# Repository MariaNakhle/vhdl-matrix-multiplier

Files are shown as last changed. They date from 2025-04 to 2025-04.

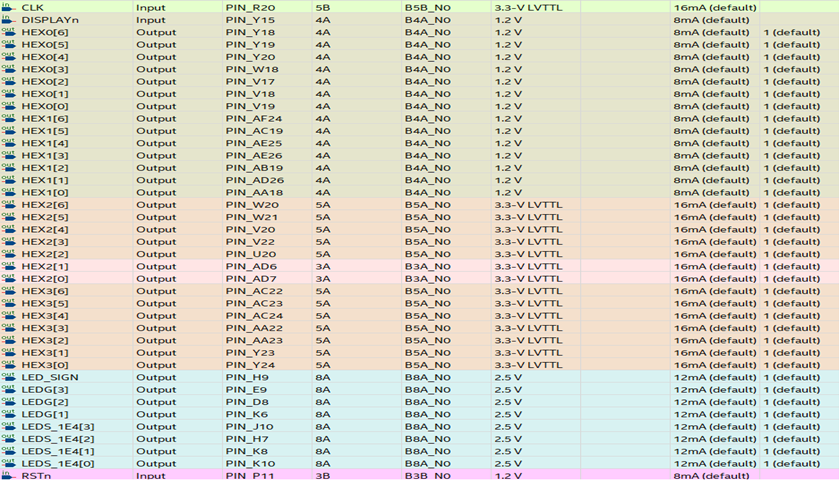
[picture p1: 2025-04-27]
assets/hardware_setup.png

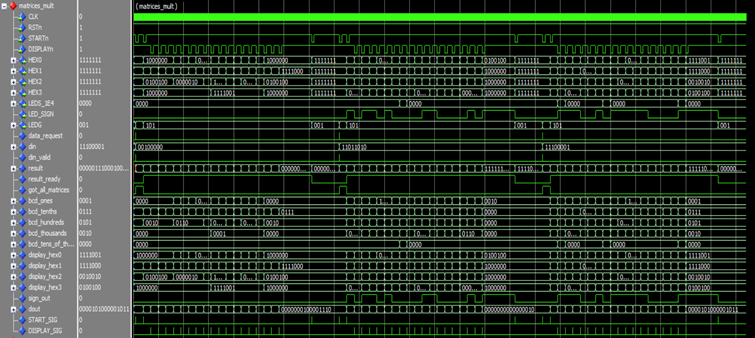
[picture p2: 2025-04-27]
assets/simulation_waveform.png

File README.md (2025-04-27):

# VHDL Matrix Multiplier - Final Project 🖩⚡

This repository contains my final project for the *Programmable Logic Devices* course at Braude College. The project demonstrates a fully functional **4×4 matrix multiplier** designed in VHDL, simulated in ModelSim, synthesized with Quartus Prime, and deployed on an Altera Cyclone V FPGA board.

---

## 📚 Project Overview

The system multiplies two signed 4×4 matrices and displays the resulting matrix on 7-segment displays. The design uses modular components, state machines, and efficient resource allocation.

---

## 🚦 Workflow

### 1. **Input Phase**
- Two 4×4 matrices are provided using a data generator.
- A `START` signal initiates the input process, storing both matrices in memory.

### 2. **Computation Phase**
- The matrix multiplier module performs the multiplication.
- The resulting matrix is saved for output.

### 3. **Output Phase**
- The result is shown on 7-segment displays.
- Additional LEDs indicate values that exceed the display range.

### 4. **Reset/Restart Phase**
- Pressing the `START` button resets the system for a new operation.

---

## 🎮 Features

### 1. Modes of Operation

- **Idle Mode:** System initializes and waits for input.
- **Input Mode:** Sequentially captures matrix elements.
- **Compute Mode:** Executes the multiplication efficiently.
- **Display Mode:** Presents each result element with navigation controls.

### 2. Control Signals

- `START`: Triggers input, computation, or resets the system.
- `DISPLAY`: Steps through the result one element at a time.

---

## 📜 Documentation

- **Project Requirements:** System requirements, design goals, and implementation plan. *(docs/Project_Requirements.pdf)*
- **Final Project Report:** Detailed explanation of design, simulation, synthesis, and conclusions. *(docs/Final_Report.pdf)*

---

## 🖼️ Visuals

### 1. System Block Diagram

A high-level overview showing the Data Generator, Matrix Multiplier, and Main Controller modules.

*Insert "Block Diagram" image here*

### 2. State Machine Diagram

- Main Controller FSM: Manages operation modes.
- Multiplier FSM: Handles multiplication steps.

*Insert "Main State Machine" and "Multiply State Machine" images here*

### 3. Simulation Results

- Example simulation waveform showing matrix multiplication outputs.

*Insert "Simulation Waveform" image here*

### 4. FPGA Hardware Setup

- Photo or schematic of the project on the Altera Cyclone V FPGA board.

*Insert "Hardware Setup" image here*

---

## 🎥 Demonstration Video

Check out a demo of the project in action:

- [Watch Matrices Multiply Video]([link-to-video](https://www.youtube.com/embed/o8P8AF92zM4?feature=oembed))
  
---

## 📂 Repository Structure

```
.
├── README.md
├── LICENSE
├── docs/
│   ├── Project_Requirements.pdf
│   └── Final_Report.pdf
├── src/                  # VHDL source files
├── tb/                   # Testbenches
├── assets/               # Block diagrams, waveforms, photos
└── reports/              # Simulation and synthesis results
```

---

## 👨‍💻 Author

- Maria

---

## 🔭 Future Improvements

- [ ] Support for larger matrices
- [ ] Pipelined or parallelized architecture
- [ ] Enhanced user interface and display modes

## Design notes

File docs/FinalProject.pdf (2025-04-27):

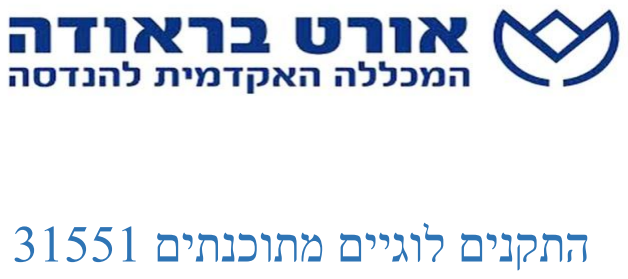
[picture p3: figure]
התקנים לוגיים מתוכנתים 31551

דוח מסכם

מגישות:

## היבא חמדאן

גנא שלבי
מריה נחלה

תאריך הגשה : 6/09/2024

מחלקה: הנדסת חשמל ואלקטרוניקה

שם המדריך: ד"ר פאדל טריף

## תוכן העניינים

.1 דרישות תכן 3 |
.2 קיצור לפעולת הבלוקים 4-5 |
.3 מימוש הרמה העליונה mult_matrices6-10 |
3.1 מבנה לוגי | 6 |
3.2 מימיוש הקוב בשפת VHDL7-9 |
10 | Pin Planner 3.3
11-16 | …Main_controller | מימוש | .4
3.1 מבנה לוגי | 11 |
3.2 מימיוש הקוב בשפת VHDL12-15 |
3.2 מכונת מצבים מתוכנתים16 |
.5 תוצאות RTL netlist Viewer עבור כל בלוק16-20 |
.6 ניצול משאבים : 21 |
.7 תוצאות ניתוח Timming22 |
.8 תוצאות מעניינות של signalTAB 23-24 |
8.1 מטריצה A | 23 |
8.2 מטריצה C | 24 |
24 | RST 8.2
.9 סרטון | 25 |
.10 סיכום | 25 |

## .1 דרישות תכן :

המערכת מופעלת משעון יחיד של 50MHz. כניסה: לחצן low active — RESET — מגיע מהלחצן שברכבה. יציאה: תצוגת מצב המערכת. מצב כל ה-LEDs ותצוגת 7n-seg יהיו כבויים למעט )1(LEDG שנמצא בכל אחד ממצבי המערכת.
לחיצה ראשונה על לחצן STARTn גורמת לבלוק generator_data להתחיל להוציא את שני המטריצות. קצב הצגת 16 האיברים בכל מטריצה הוא תוצאה ללחיצה הראשונה ולאחר כל 16 האיברים של המטריצה קדימה או אחורה המערכת עוצרת ומחכה ללחיצה נוספת. בזמן קבלת המטריצות המערכת מתעלמת מלחיצות על הלחצנים STARTn -1DISPLAYn. גודל המטריצות 44x כאשר כל איבר במטריצה הוא מספר של 8 signed bits( מספרים מוסומנים בין - 127 ל127+(.
התוצאה תרשם בזיכרון בסדר שהוכן בזיכרון לאחר קבלת תוצאות המטריצות, המערכת תעבור לתצוגת התוצאות.
אם לחצן STARTn נלחץ שוב במהלך תצוגת התוצאות, המערכת תמשיך להתעלם מלחיצות על הלחצנים .STARTn- ו DISPLAYn-1
המערכת תפעל בסבב של שתי מטריצות ותתקבלנה תוצאות גם אם היא לא לחוצה בזמן כתיבת תוצאות. לחיצה על לחצן אחר תגרום לשינוי תצוגת מצב המערכת על ה-LED ותצוגת 7n-seg. במהלך קבלת המטריצות, לחיצה על לחצן אחר לא תגרום לשינוי תצוגת מצב המערכת על ה- LED ותצוגת .seg-n7
לאחר שהתוצאה הראשונה של המטריצות תתקבל ותוצג, תופעל לחיצה נוספת שתפעיל את התצוגה הבאה.
במצב תצוגת המטריצות המערכת חוזרת לתצוגת מצב המערכת על STARTn -1DISPLAYn. המערכת תמשיך בתצוגה זו עד אשר תתקבל תוצאה ברורה )אין אפשרות לבצע קריאת זיכרון וכתיבה לזיכרון בו זמנית(.
במהלך הצגת התוצאה המערכת מציגה את התוצאה באמצעות הלחצנים במטריצה של 7n-seg. לחיצה על כל לחצן אחר תגרום להצגת התוצאה באופן אוטומטי. לחיצה נוספת על לחצן STARTn תגרום להפסקת התצוגה ולהפעלת המערכת מחדש לתחילת התהליך.

## .2 קיצור לפעולת הבלוקים שקיבלנו מד"ר פאדל :

:bcd_to_7seg | הבלוק | מימוש

הקוד ממיר ערך BCD בן 4 ביט ) 0-9( לתצוגת 7 סגמנטים על ידי קביעת אילו סגמנטים ידלקו עבור כל ספרה.
מימוש הבלוק generator_data :

הבלוק מתפקד כגנרטור נתונים שמייצר ומעביר נתונים מחוץ לרכיב בצורה מאורגנת ומבוקרת, כאשר כל פעם שמתקבל REQUEST_DATA, הוא שולח סדרה של נתונים מהמטריצות שלו דרך האות DOUT.
:bin2bcd_12bit | הבלוק | מימוש

ממיר מספר בינארי בגודל 16 סיב ית )12 סיביות לוגיות בלבד( לפורמט BCD עם 5 ספרות )כולל עשרות אלפים, אלפים, מאות, עשרות, ויחידות(.

מימוש הבלוק convert_num:

הרכיב לוקח מספר בינארי עם סימן, מפריד את הסימן וממיר את המספר לחיובי, ומוציא את התוצאה יחד עם הסימן המקורי. מימוש הבלוק diff_synic:

הרכיב מסנכרן אות כניסה אסינכרוני עם שעון המערכת ומפיק פלט שמציין שינוי באות בהתאם להגדרה.
מימוש הבלוק ram_matrix:

הקוד מייצג רכיב זיכרון RAM שניתן לכתוב ולקרוא ממנו נתונים על פי כתובת.

מימוש הבלוק multiplier_my:

הרכיב מבצע כפל בין שני מספרים בינאריים.

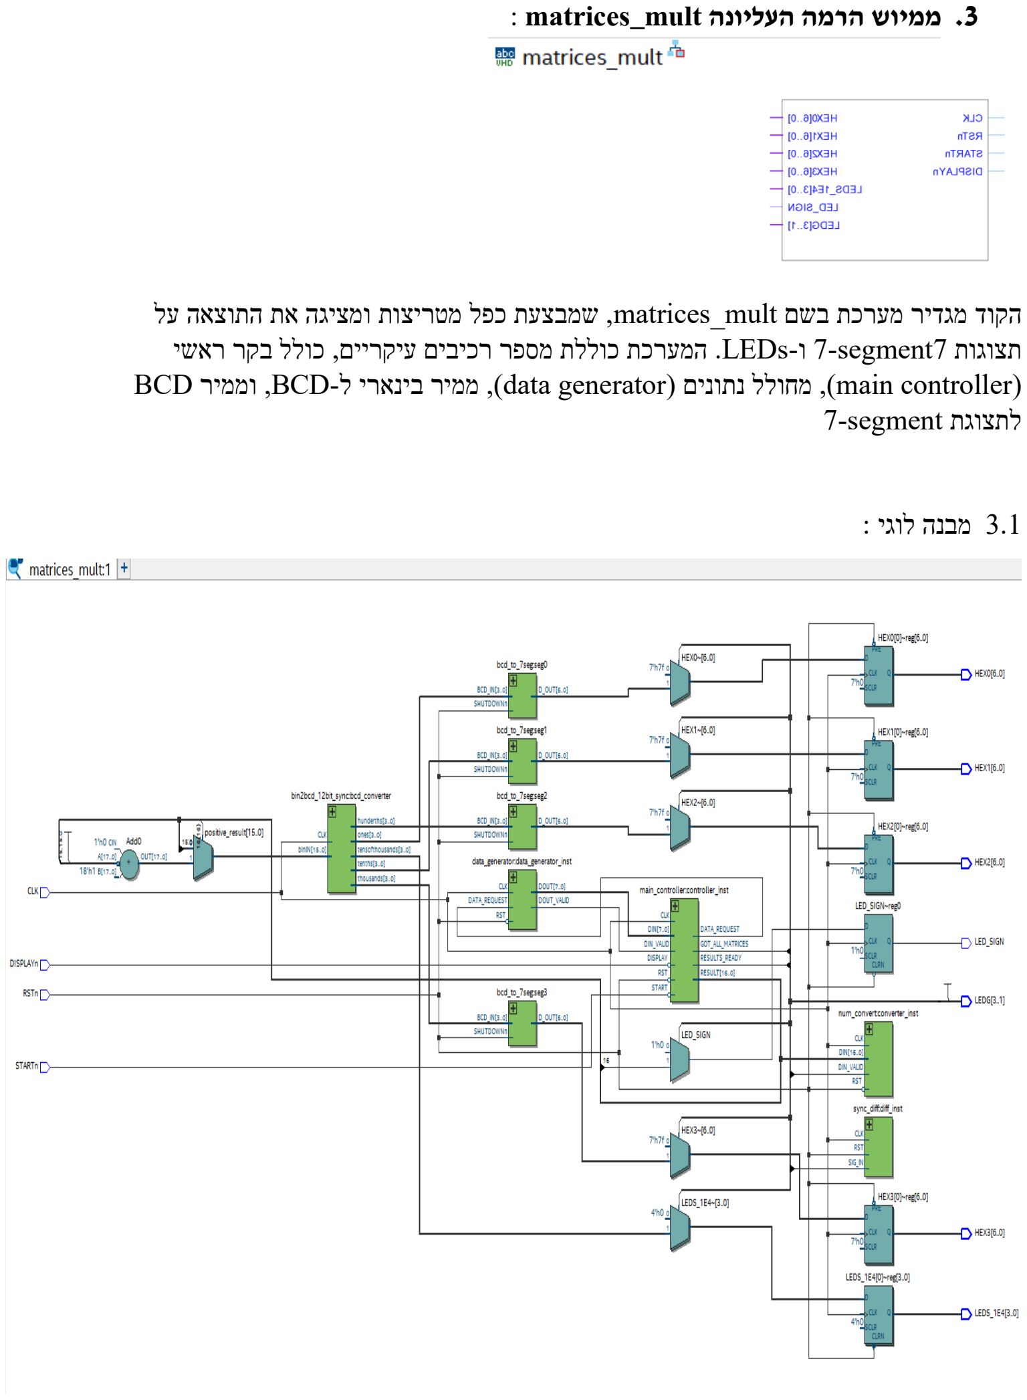
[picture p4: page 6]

.3 ממיוש הרמה העליונה mult_matrices :

הקוד מגדיר מערכת בשם mult_matrices, שמבצעת כפל מטריצות ומציגה את התוצאה על תצוגות 7segment7- ו-LEDs. המערכת כוללת מספר רכיבים עיקריים, כולל בקר ראשי )controller main), מחולל נתונים )generator data), ממיר בינארי ל-BCD, וממיר BCD לתצוגת segment7-

3.1 מבנה לוגי :

: matrices_mult.vhd | קובץ | 3.2

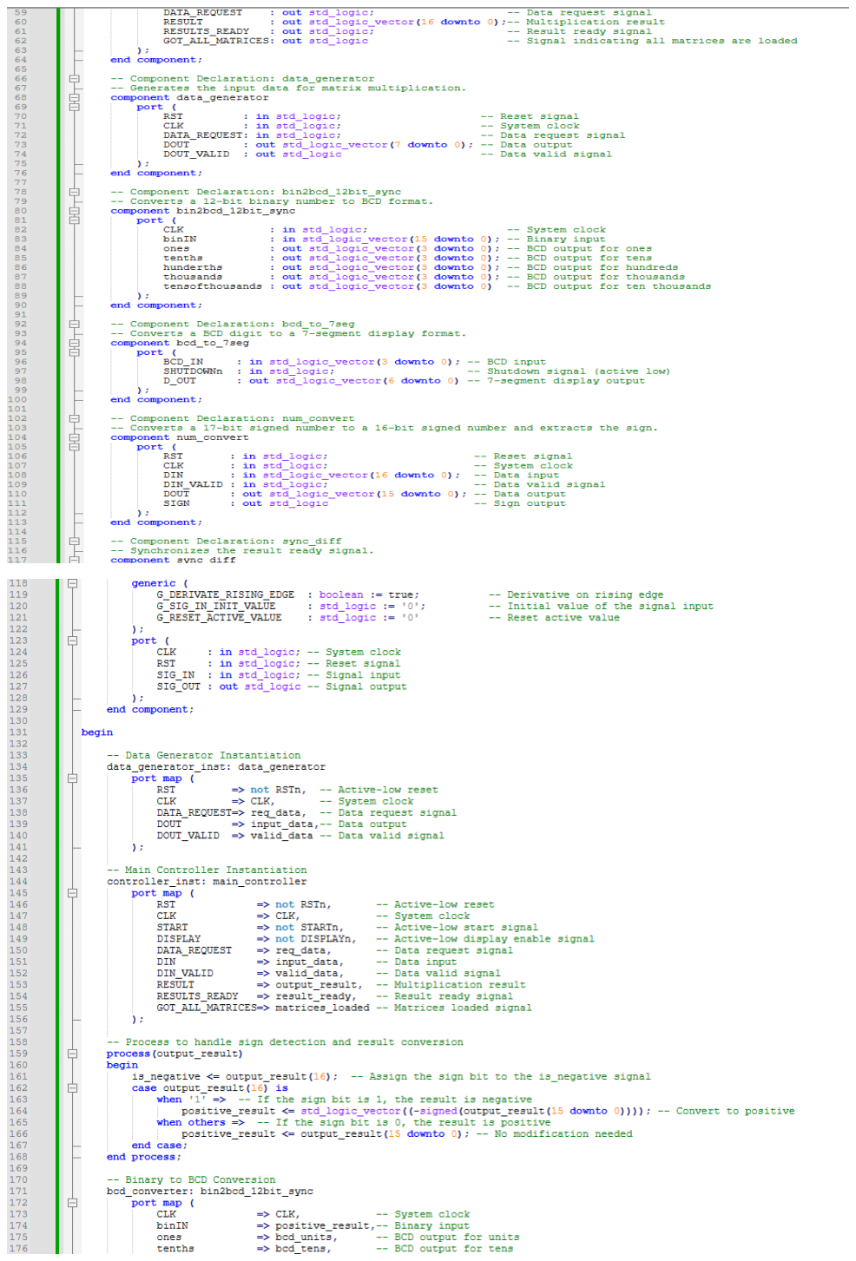
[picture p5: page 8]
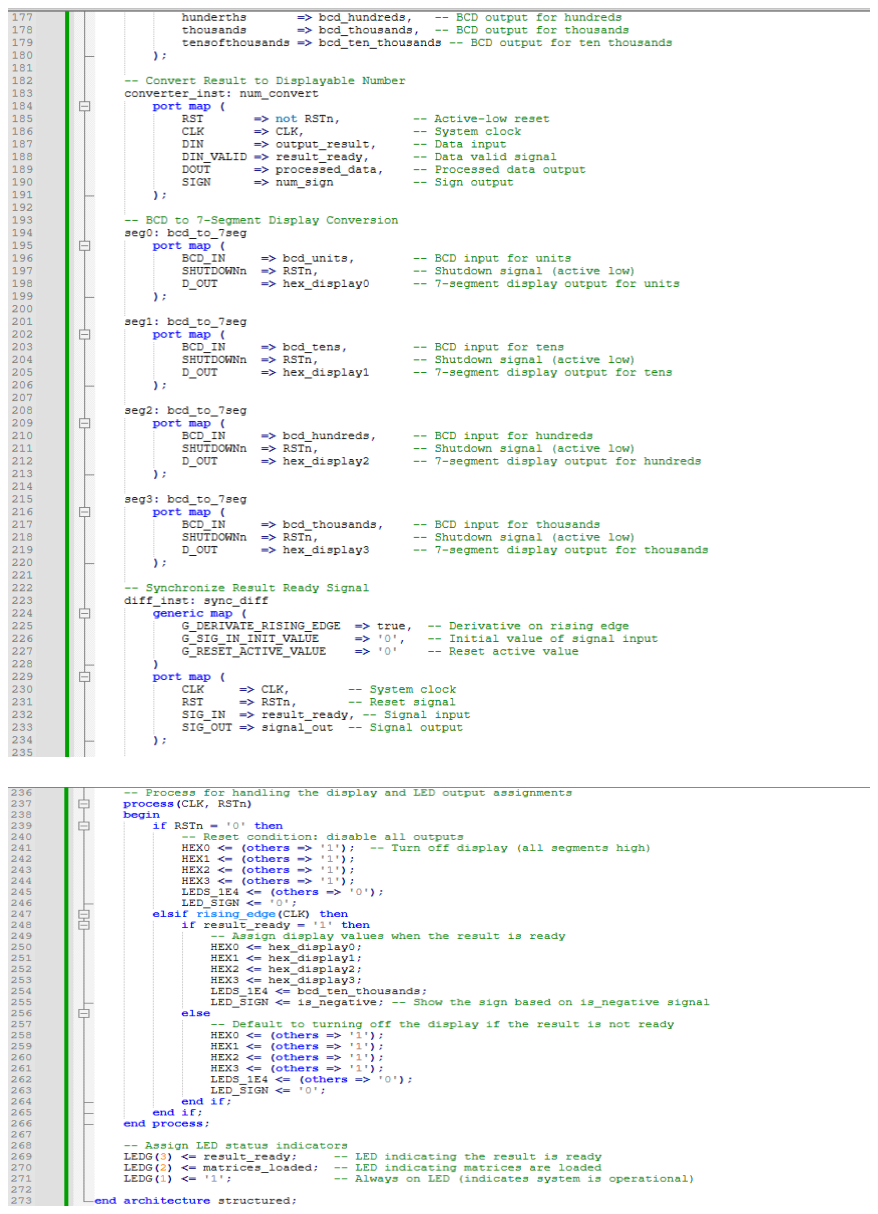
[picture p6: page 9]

## : Pin Planner 3.3

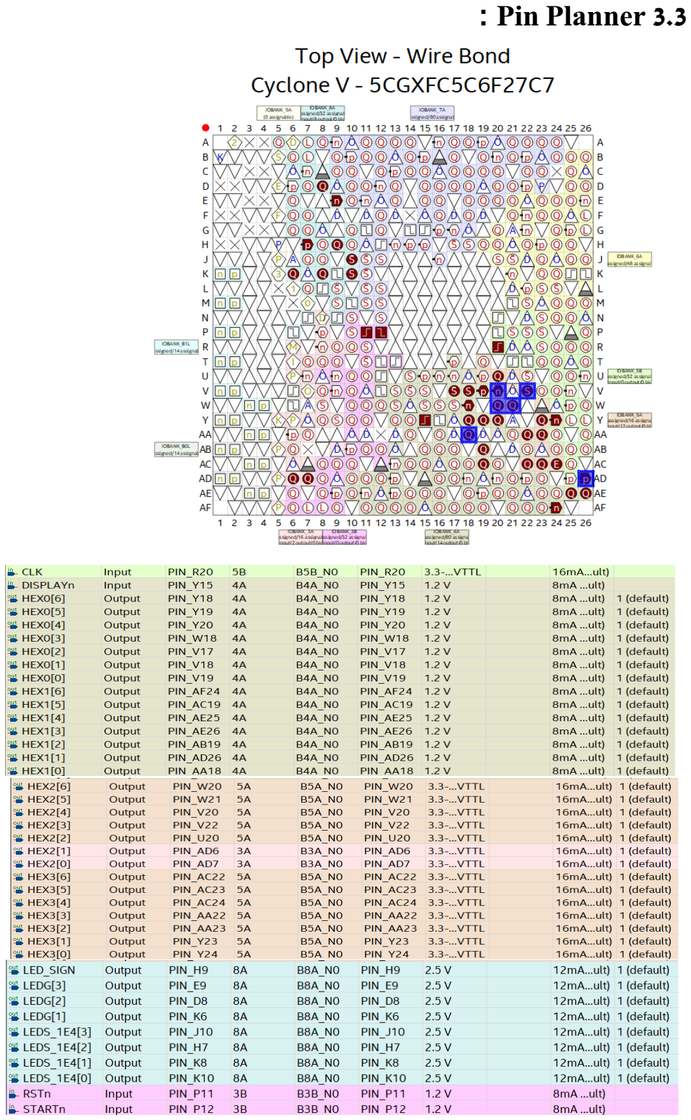
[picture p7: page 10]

.4 מימוש הבלוק controller_main:

הבלוק controller_main הוא רכיב הבקרה המרכזי של המערכת, והוא אחראי על ניהול כל תהליך כפל המטריצות והצגת התוצאות על תצוגות segment7- ו- LEDs. הבלוק מקבל את הפקודות מהמשתמש באמצעות לחצנים )DISPLAY ,START )לאחר שעוברים תהליך של סנכרון וזיהוי עליות אותות, ופועל בהתאם לפקודות שניתנו,הבלוק שולח פולס של REQUEST_DATA לבלוק generator_data כדי לבקש את נתוני המטריצות. לאחר מכן, הבלוק מתחיל לקלוט את המידע ולהעבירו לזיכרון פנימי לשימוש בחישובים.טוען שתי מטריצות בזיכרון, אחת אחרי השנייה. במהלך שלב זה, הבלוק מעדכן מונים ואינדקסים כדי לעקוב אחרי מיקומי המידע בזיכרון ולוודא שכל הנתונים נטענים בצורה נכונה. עם סיום טעינת המטריצות, הבלוק מאותת באמצעות MATRICES_ALL_GOT שהמטריצות נטענו בהצלחה. הבלוק מנהל את פעולת רכיבי הכפל )multiplier_my )ומוודא שכל תוצאת כפל נשמרת בצורה נכונה בזיכרון
על תצוגות segment7- ו הפעלת נורות LED חיווי בהתאם למצב הנוכחי של התוצאה המחושבת. במידה ותוצאה שנבדקת נמצאה כלא תקינה, תידלק נורת חיווי אדומה )SIGN_LED). כאשר כל המידע מוצג והתהליך מסתיים, לחיצה נוספת על לחצן ההתחלה )START )מאפסת את המערכת ומכבה את כל נורות החיווי )לדים ירוקים ואדום(, ומחזירה את המערכת למצב המתנה ) IDLE).

4.1 מבנה לוגי :

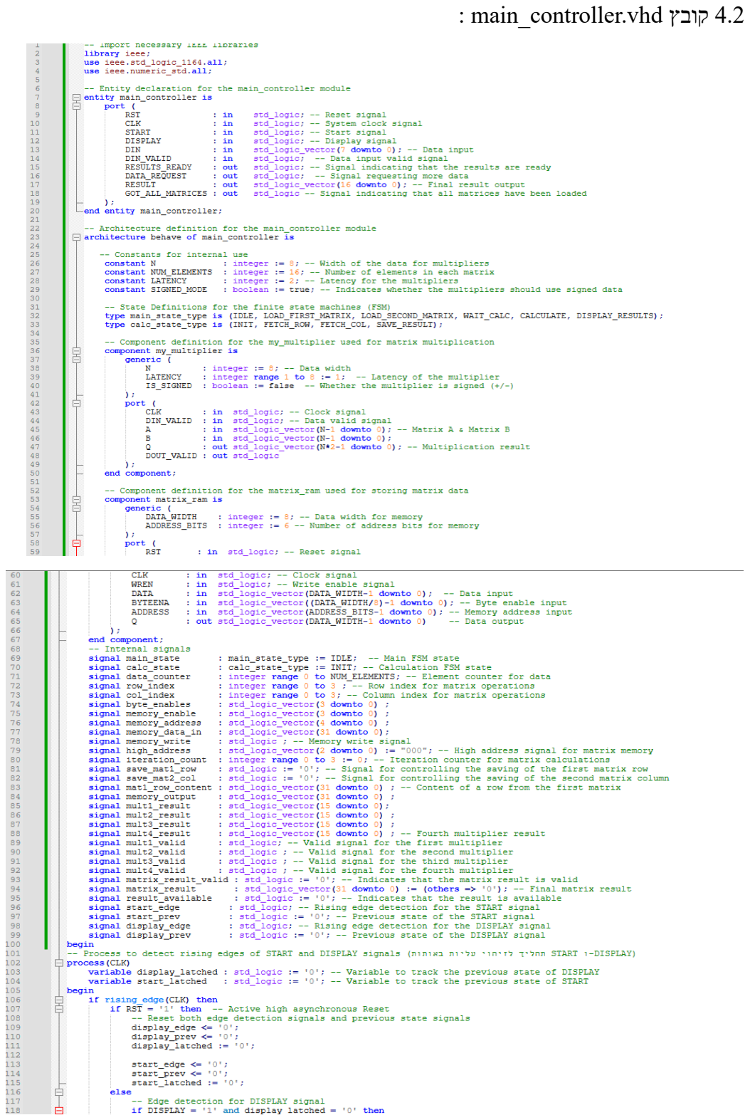
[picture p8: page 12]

: main_controller.vhd | קובץ | 4.2

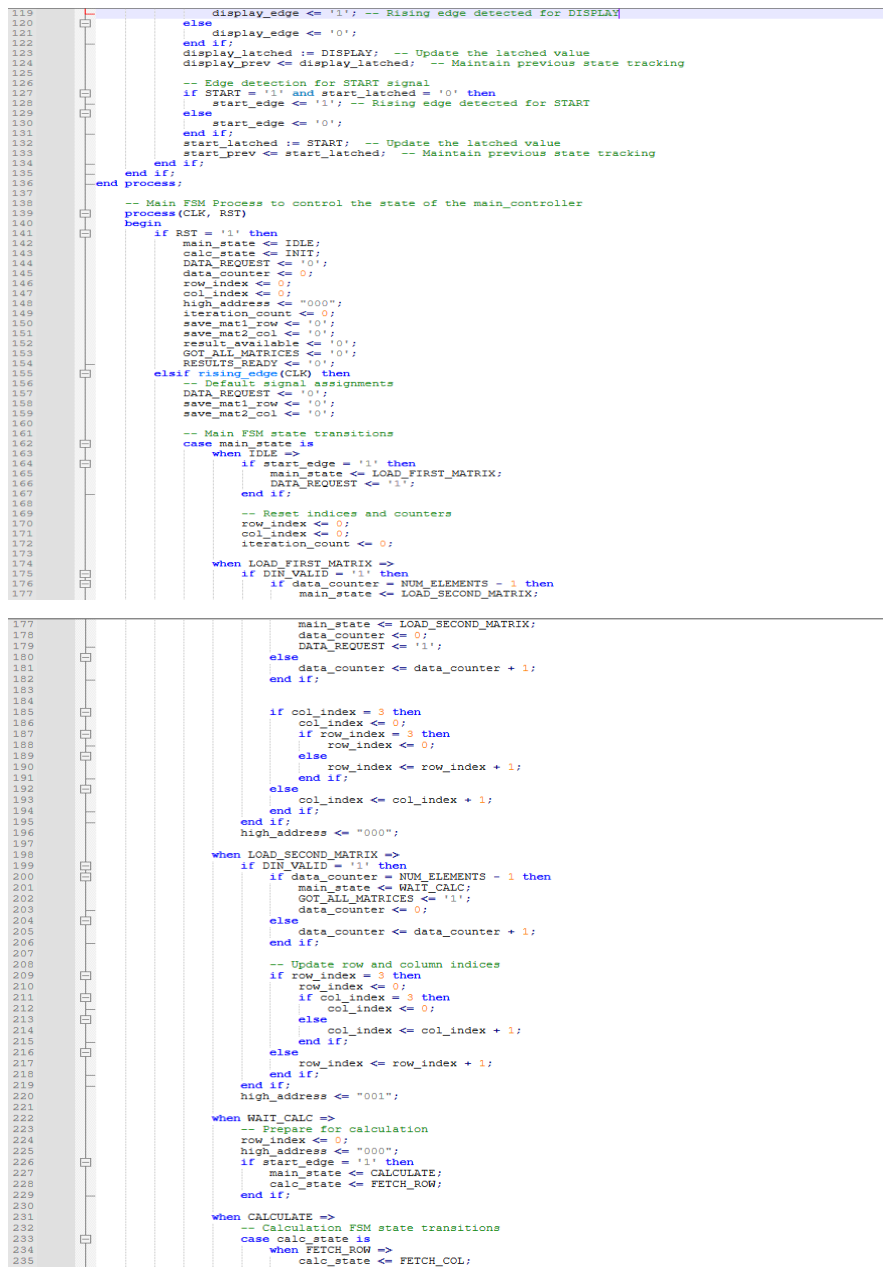
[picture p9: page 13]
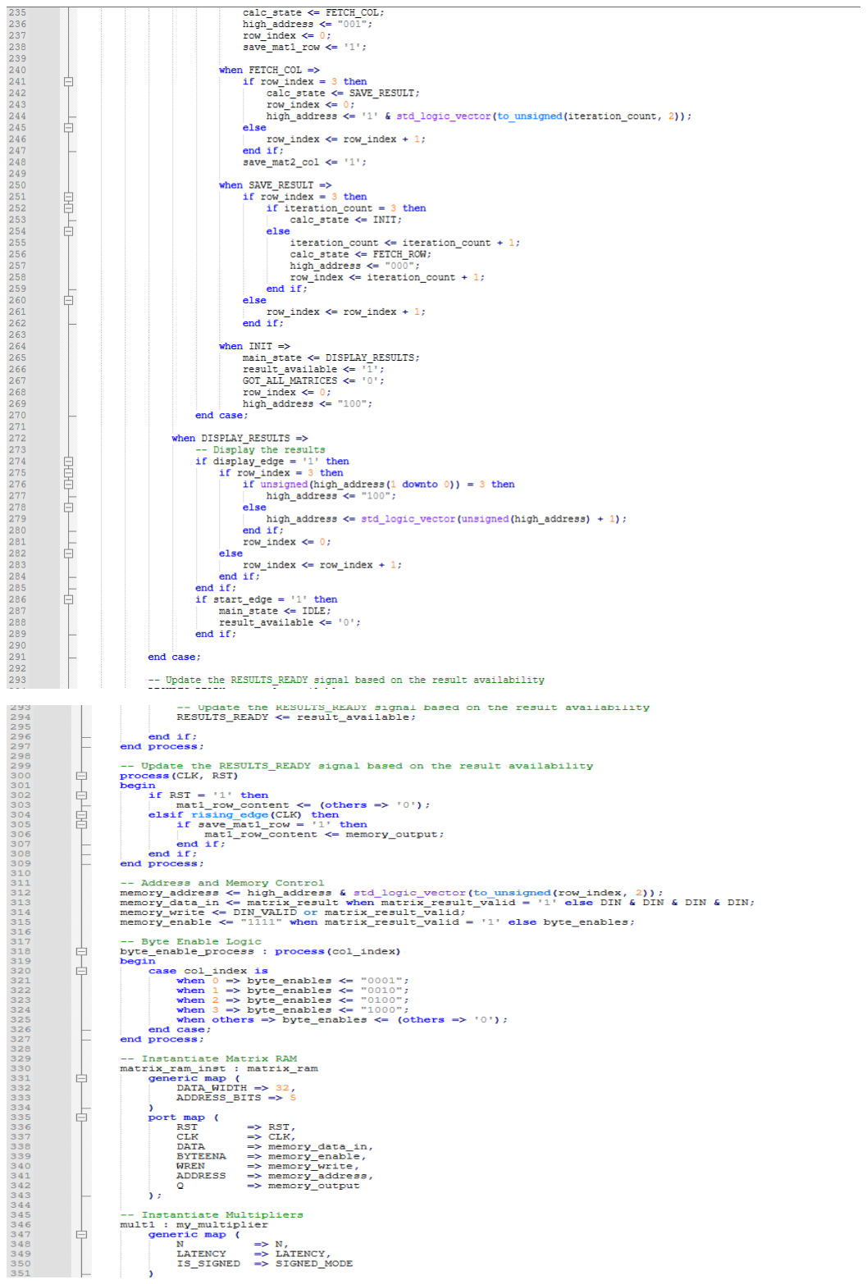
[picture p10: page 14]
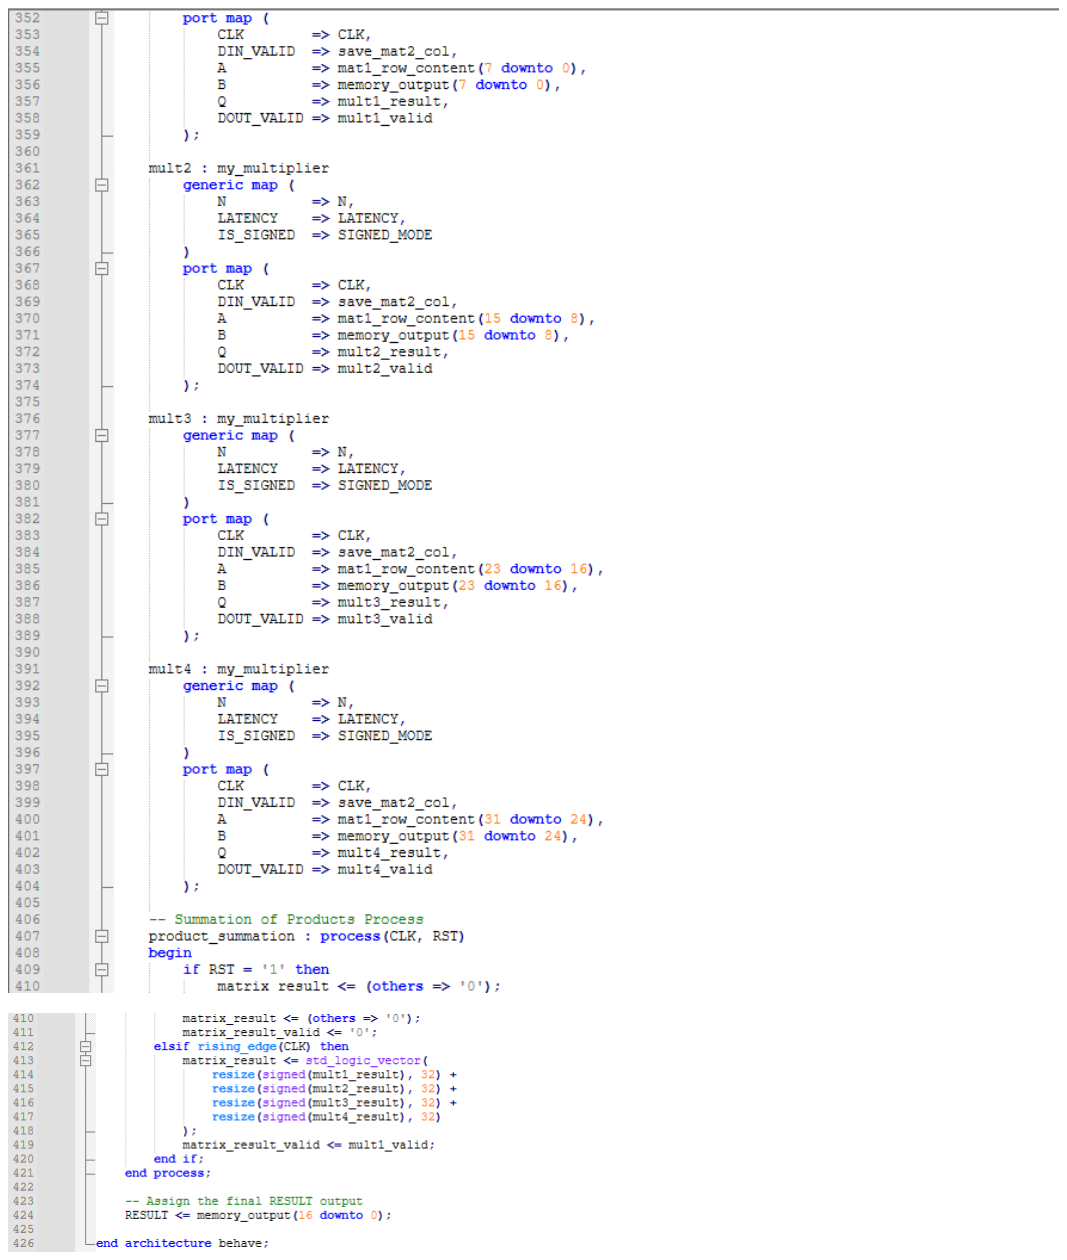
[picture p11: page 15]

### 4.3 מכונות מצבים :

מבנה לוגי 1 :

המערכת מתחילה במצב INIT לאחר שהיא מקבלת פקודת reset .

אם `1`=edge_start המכונה מעבירה ל ROW_FETCH-כדי ל אסוף שורה מהמטריצה הראשונה לאחר איסוף שורה, המכונה מעבירה ל COL_FETCH-כדי לאסוף עמודה מהמטריצה השנייה לאחר איסוף העמודה, אם כל השורות הוקראו המכונה מעבירה ל RESULT_SAVE- שבו שומרים את התוצאות שהתקבלו מהכפל.אם לא כל השורות הוקראו, המכונה ממשיכה לאסוף את שאר השורות.

אם 3=index_row ו 3=count_intration וכל האיטרציות הושלמו המכונה חוזרת ל INIT לשלב הבא של חישוב.
מבנה לוגי 2 :

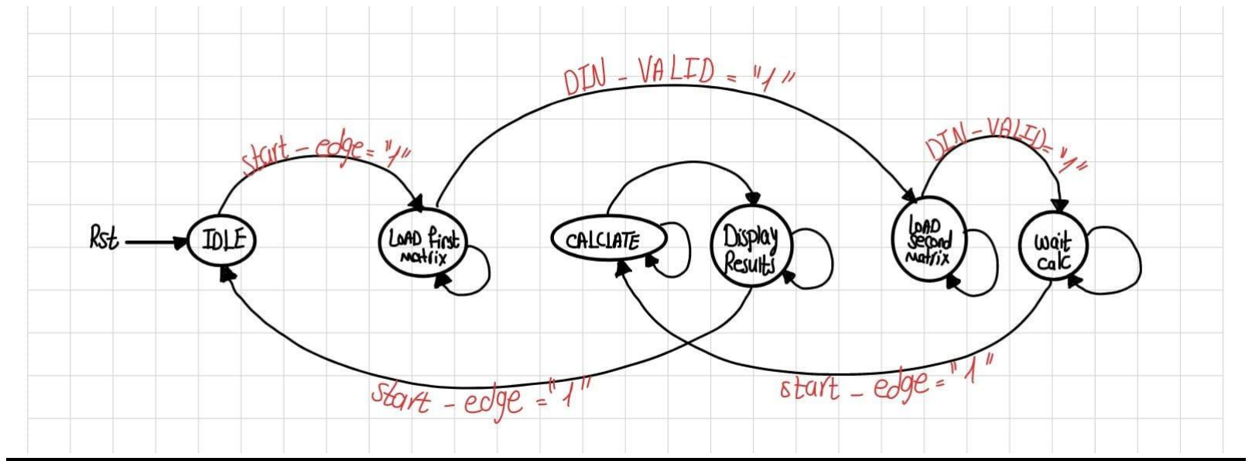
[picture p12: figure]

המערכת מתחילה במצב IDLE לאחר שהיא מקבלת פקודת RST. אם `1`=edge_start המכונה עוברת ל MATRIX_FIRST_LOAD- במצב זה, המערכת טוענת את המטריצה הראשונה כאשר המטריצה הראשונה נטענה בהצלחה אם `1`=VALED_DIN המכונה מעבירה ל.MATRIX_SECOND_LOAD- לטעון את המטריצה השנייה לאחר טעינת המטריצה השנייה, המערכת יכולה להמתין להמשך חישוב במצב CALC_AWAIT. אם `1`=edge_start המערכת עוברת למצב CALCULATE כדי לבצע את החישובים הנדרשים. אם החישוב הושלם ואין צורך במטריצה נוספת, המערכת עוברת למצב RESULTS_DISPLAY להצגת התוצאות. לאחר הצגת התוצאות, המערכת יכולה לחזור למצב IDLE ולהמתין לתהליך חדש או לקבל פקודה נוספת.

## .5 תוצאות RTL netlist viewer עבור כל בלוק והרמה העליונה :

## עבור הרמה העליונה mult_matrices:

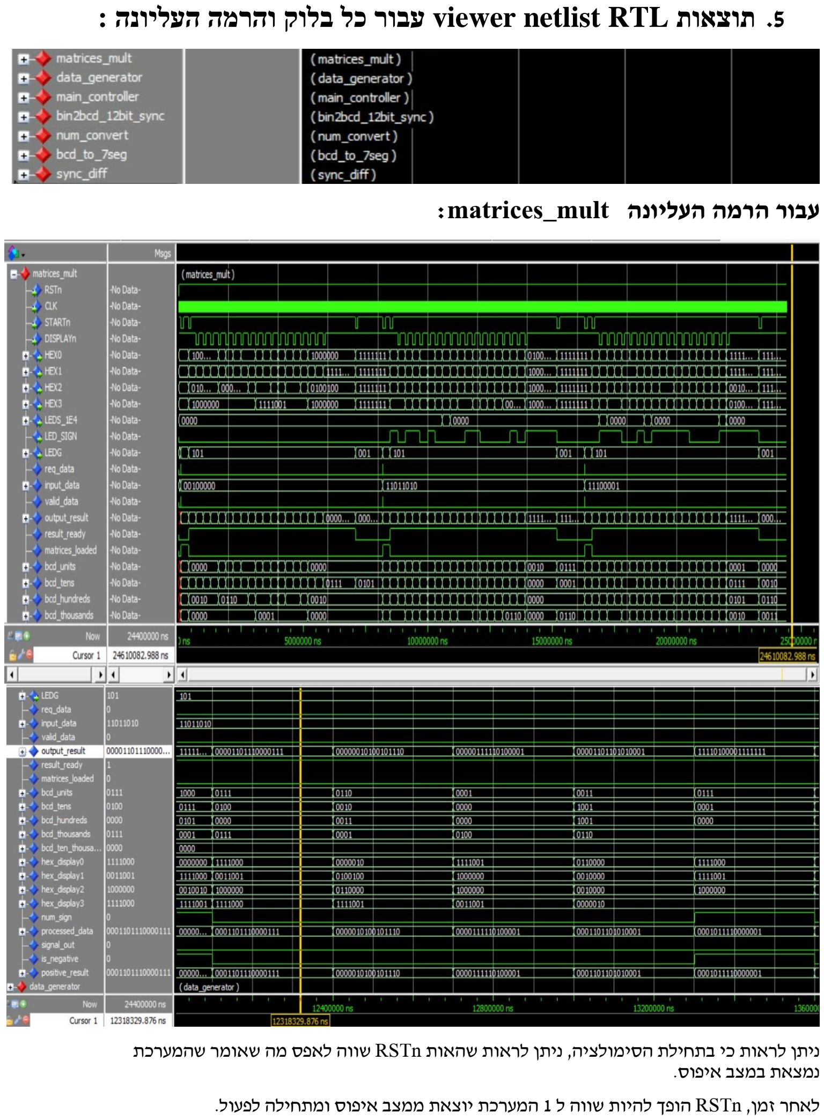
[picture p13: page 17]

ניתן לראות כי בתחילת הסימולציה, ניתן לראות שהאות RSTn שווה לאפס מה שאומר שהמערכת נמצאת במצב איפוס.
לאחר זמן, RSTn הופך להיות שווה ל 1 המערכת יוצאת ממצב איפוס ומתחילה לפעול.

ברגע שכל הנתונים נטענים ) 1 = loaded_matrices), המערכת מתחילה את חישוב כפל המטריצות. ניתן לראות שעם הזמן, result_output מתחיל להשתנות ומציג את התוצאה של כפל המטריצות. כאשר ready_result הופך ל ,1- התוצאה מוכנה להצגה. התוצאות מופיעות על תצוגות segment7-) 3HEX - 0HEX (וה -LEDs בהתאם לערכים המחושבים .)'וכו ,bcd_units, bcd_tens( SIGN_LED מציין את הסימן של התוצאה. 4E1_LEDS מציג את הערך של ספרת עשרת אלפים אם נדרש. LEDG מדליקים את נורות ה-LED המתאימות המציינות שהמערכת פועלת והתוצאה מוכנה.

: data_generator | עבור

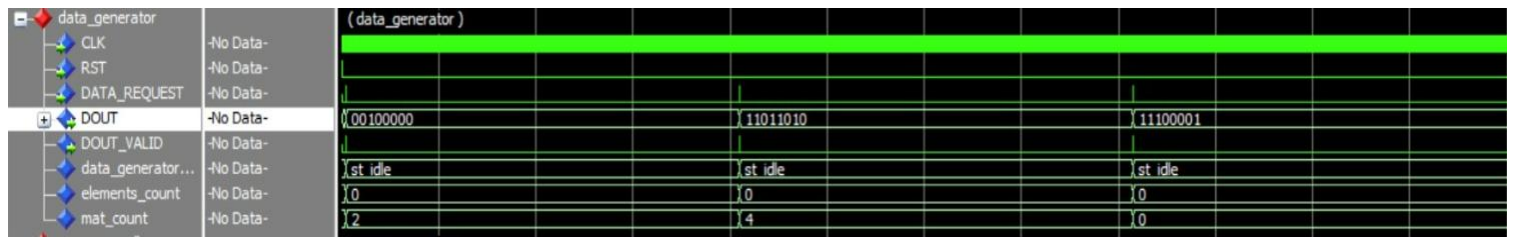
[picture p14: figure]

:synic_diff | עבור

ניתן לראות מסימולציה הפלט מציג את השינויים באות IN_SIG לאחר הסנכרון והגזירה. ו ניתן לראות שהוא מפיק פלט מסונכרן OUT_SIG רק כשהוא מזהה שינוי מתאים ב -IN_SIG.

## :main_controller עבור

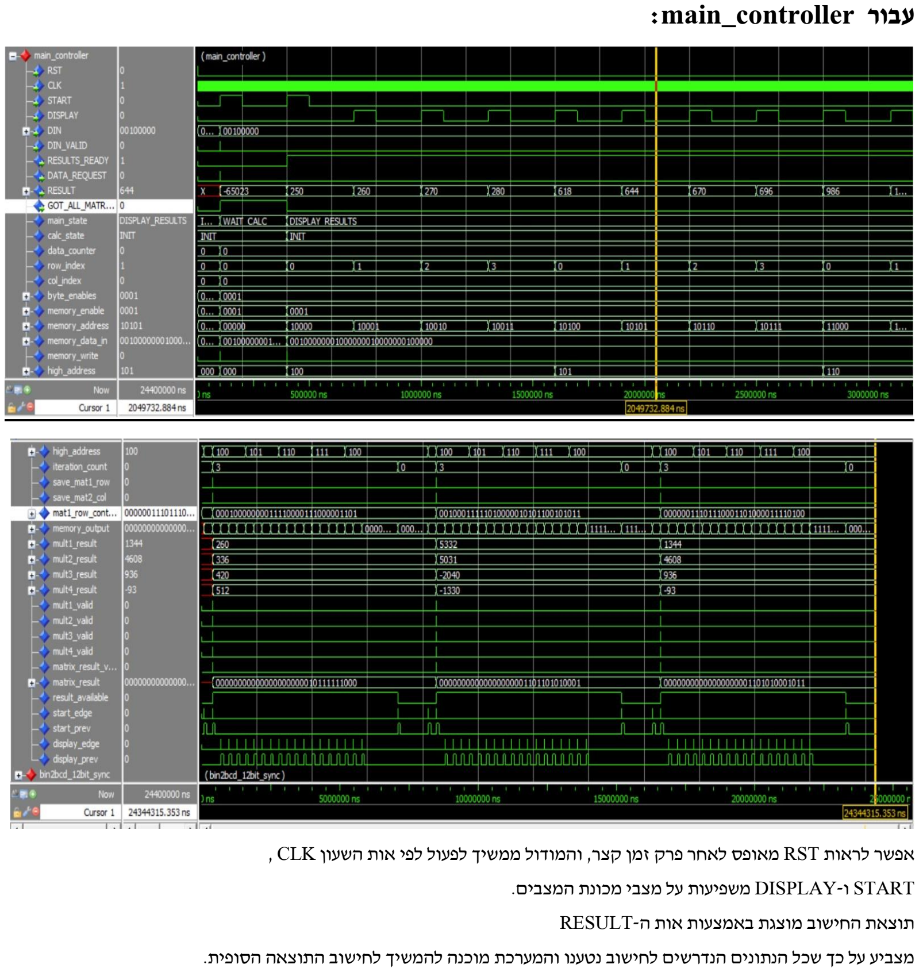
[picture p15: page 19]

אפשר לראות RST מאופס לאחר פרק זמן קצר, והמודול ממשיך לפעול לפי אות השעון CLK ,

START ו-DISPLAY משפיעות על מצבי מכונת המצבים.

תוצאת החישוב מוצגת באמצעות אות ה-RESULT

מצביע על כך שכל הנתונים הנדרשים לחישוב נטענו והמערכת מוכנה להמשיך לחישוב התוצאה הסופית.

:bin2bcd_12bit עבור

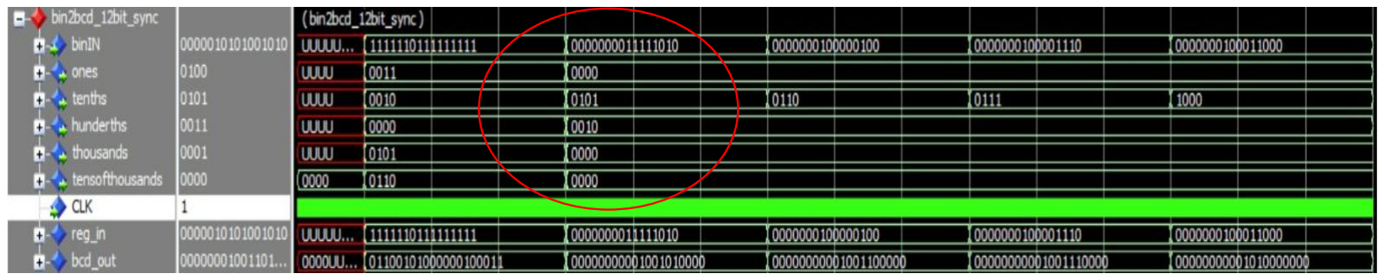
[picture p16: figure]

ניתן לראות מהסימולציה שהוא מממיר המספר הבינארי 0000000011111010 שזה שווה ל 250 בבסיס עשרוני ומפריד אותו לתוך הספרות אחדות עשרות מאות אלפים עשרות האלפים כך ש באחדות מקבלים 0000 )0 בבסיס עשרוני(, עשרות מקבלים 0101 )5 בבסיס עשרוני( מאות 0010 )2 בבסיס עשרוני ( והשאר ממלא אפס .
:num_convert עבור

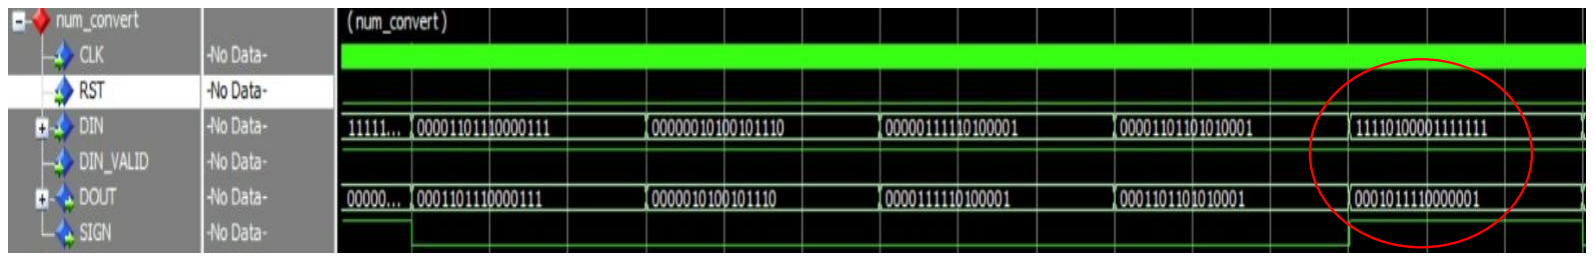
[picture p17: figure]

ניתן לראות מהסימולציה שהמספר החיו בי נשאר אותו דבר ללא שינוי. מתוך העיגול האדום נזהה שהמספר 11110100001111111 זהו מספר שלילי בגלל ביט הסימן )1( נהפוך את כל הביטים ונקבל 0001011110000000 נוסיף 1 למספר המהופך ,0001011110000000 התוצאה היא 0001011110000001 מאחר וזה היה מספר שלילי מקבלים DOUT התוצאה המוחלטת היא 000101111000001 שמייצג את הערך המוחלט של 6017 בעשרוני. :bcd_to_7seg עבור

ניתן לראות בסימולציה כל ערך שנכנס למערכת מתורגם לערך שמסמל איזה לידים צריכים להידלק בצג שעל הערכה (הלדים נדלקים בנמוך).המוצא תלוי ב- SHUTDOWN, כלמור כאשר הוא אפס המצוא יהיה ‘1111111’זאת אומרת ה- segment 7 של הערכה יהיה כבוי, וכאשר ‘1’ = SHUTDOWN המערכת תעבוד בדיוק כמו בסימולציה.

## .6 ניצול משאבים :

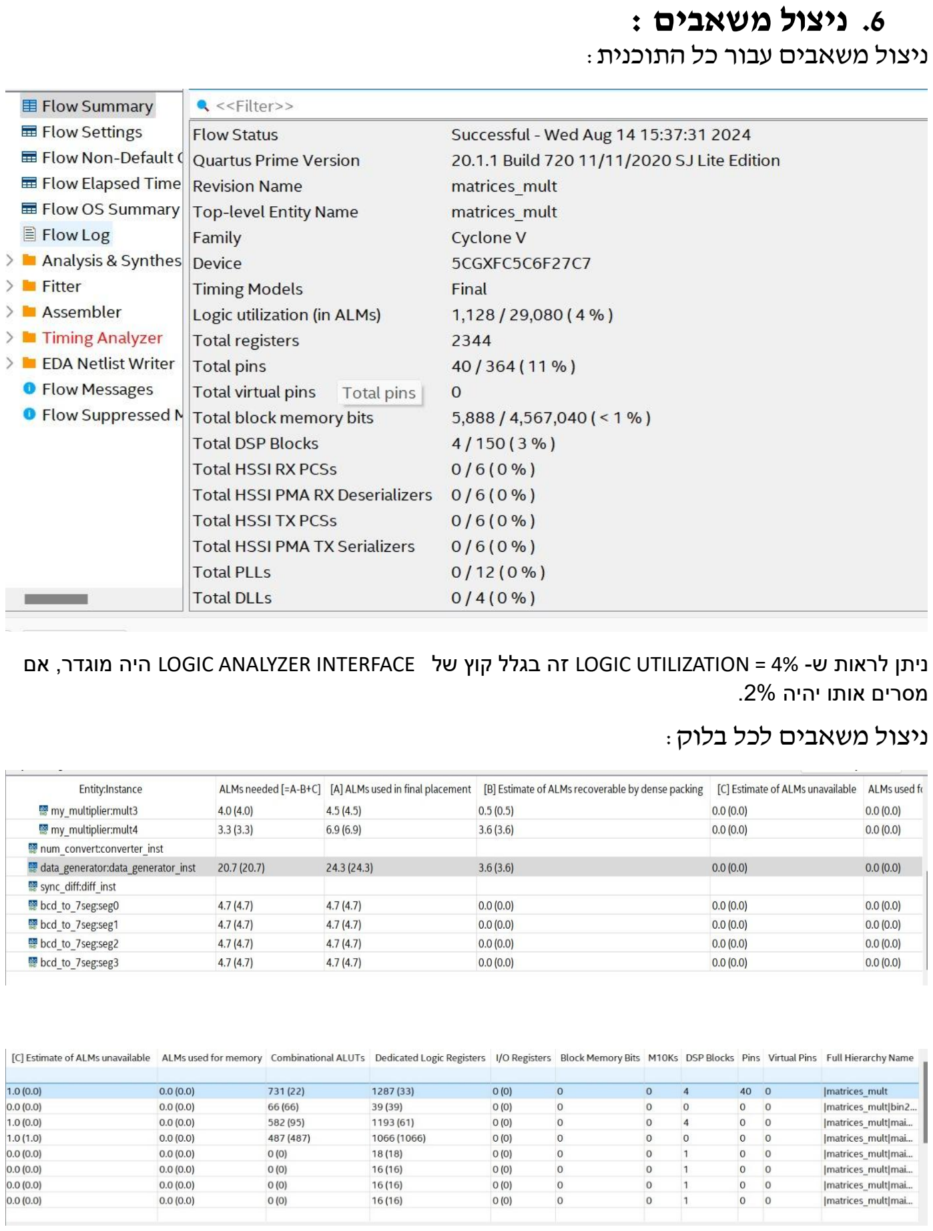
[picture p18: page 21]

ניצול משאבים עבור כל התוכנית:

ניתן לראות ש- 4% = UTILIZATION LOGIC זה בגלל קוץ של INTERFACE ANALYZER LOGIC היה מוגדר, אם מסרים אותו יהיה .2%
ניצול משאבים לכל בלוק:

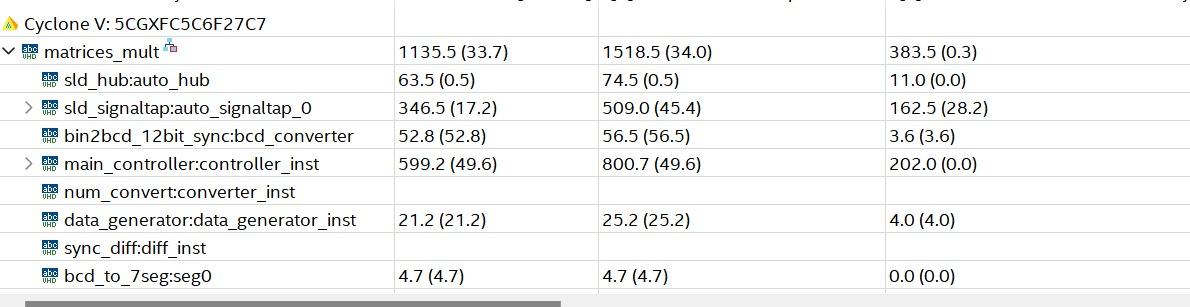
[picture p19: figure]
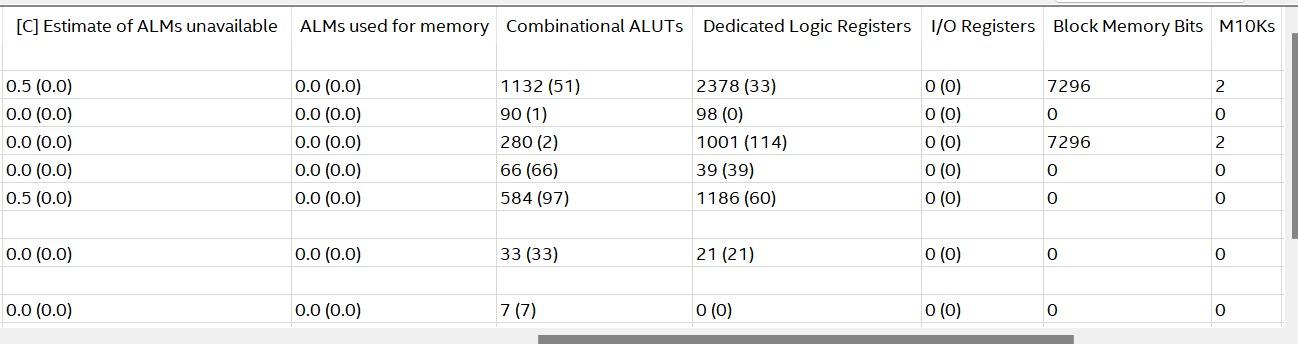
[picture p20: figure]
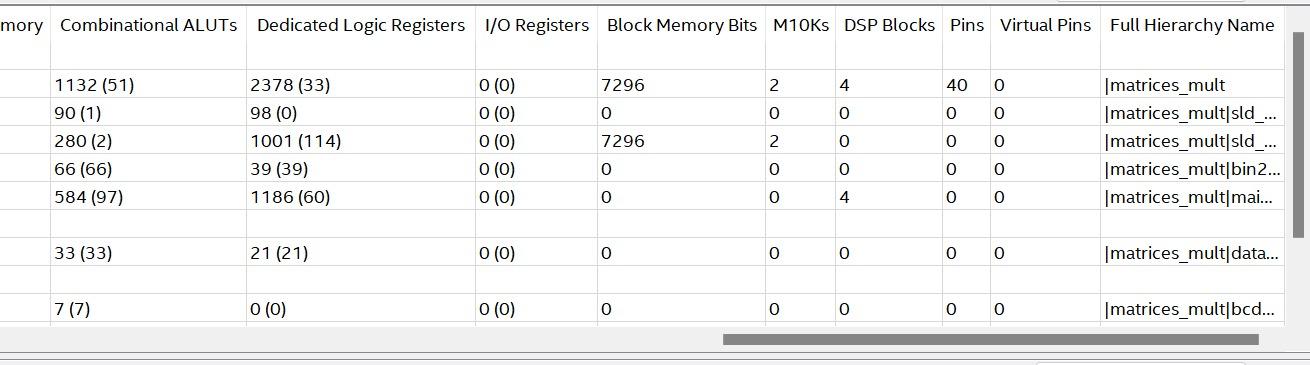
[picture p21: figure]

## .7 תוצאות מעניינות של SignalTAB

בדיקה עבור לחיצת DISPLAYn:

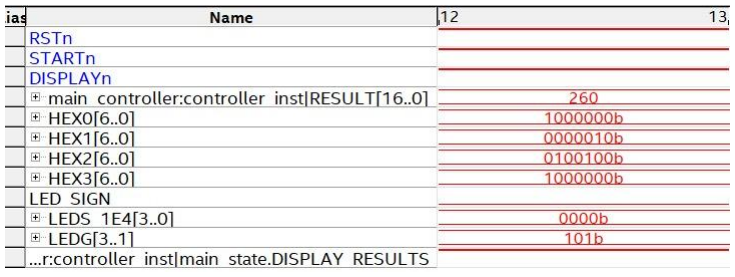
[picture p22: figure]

7.1 עבור מטריצה A :

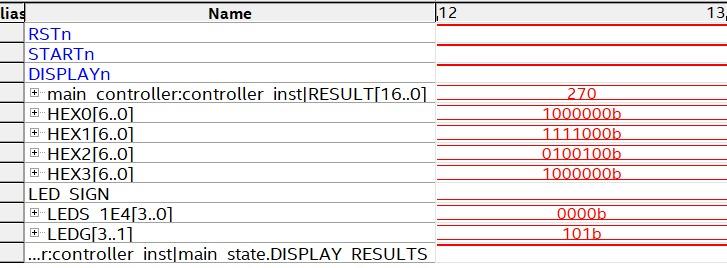
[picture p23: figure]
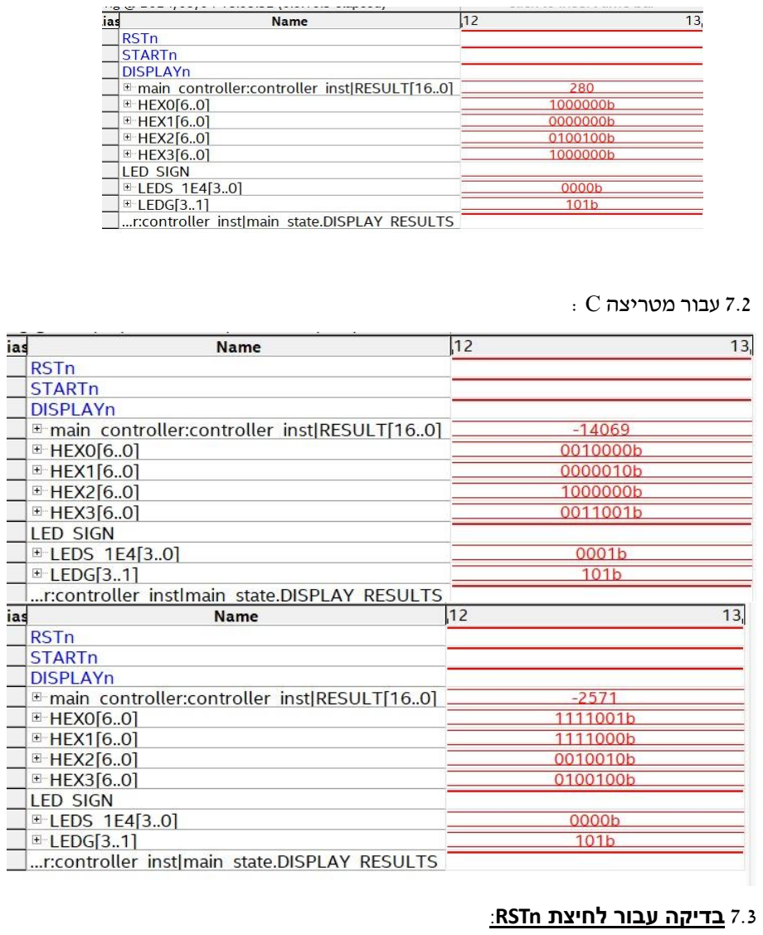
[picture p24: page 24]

7.2 עבור מטריצה C :

7.3 בדיקה עבור לחיצת RSTn:

7.3 בדיק ה עבור לחיצת STARTn:

לחיצה ראשונה:

לחיצה שניה:

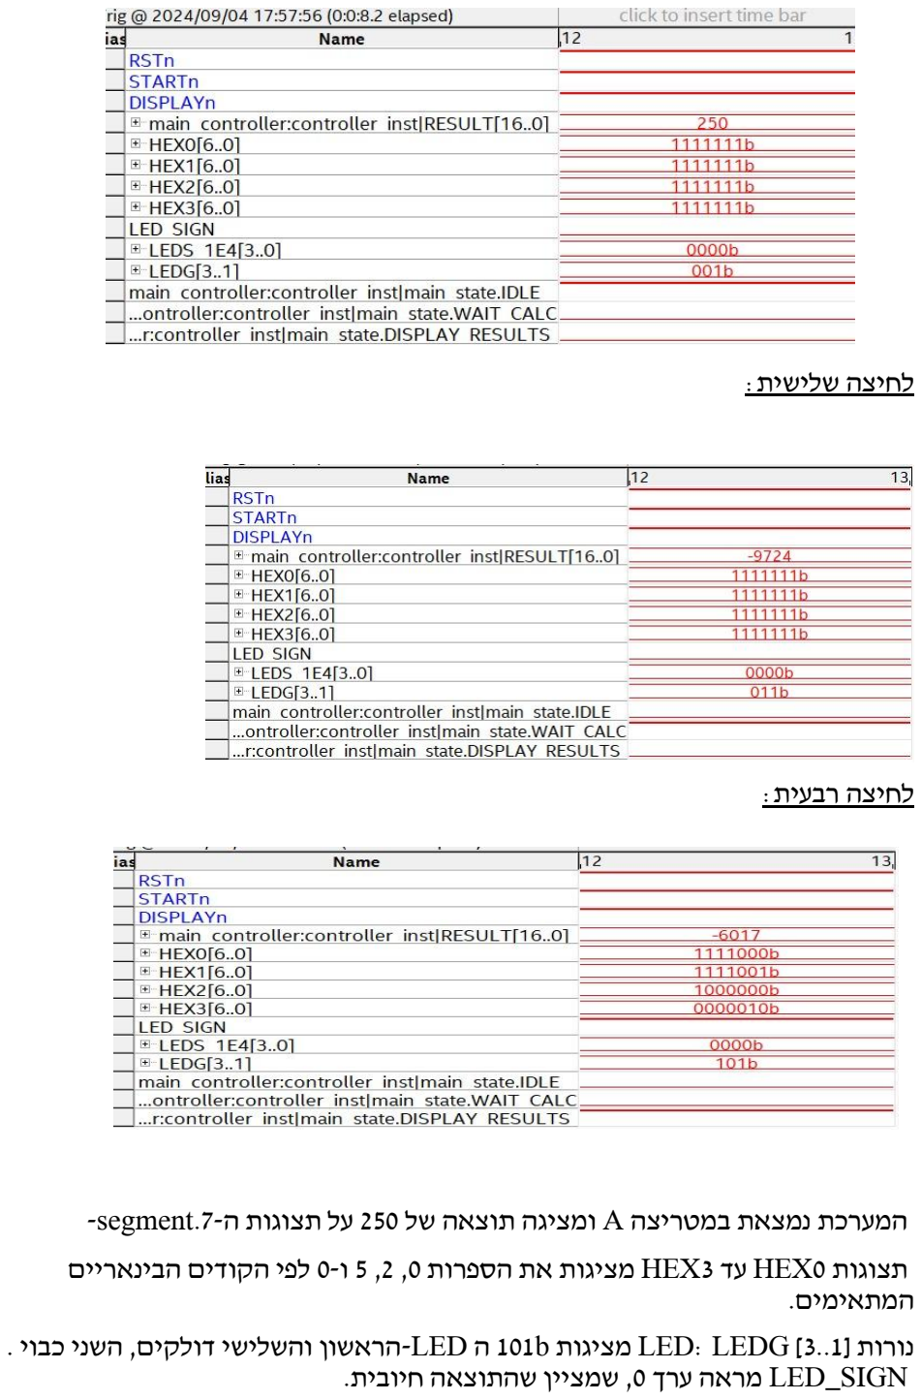
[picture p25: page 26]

לחיצה שלישית:

לחיצה רבעית:

המערכת נמצאת במטריצה A ומציגה תוצאה של 250 על תצוגות ה.7-segment-תצוגות 0HEX עד 3HEX מציגות את הספרות ,0 ,2 5 ו- 0 לפי הקודים הבינאריים המתאימים.
נורות [3..1] LEDG :LED מציגות b101 ה LED-הראשון והשלישי דולקים, השני כבוי . SIGN_LED מראה ערך ,0 שמציין שהתוצאה חיובית.

המערכת | -st_display: ו st_idle, st_wait_for_calculate בין | עוברת | המצבים | מכונת
מתחילה במצב המתנה, מחכה לחישוב ואז מציגה את התוצאה.

## .8 סרטון:

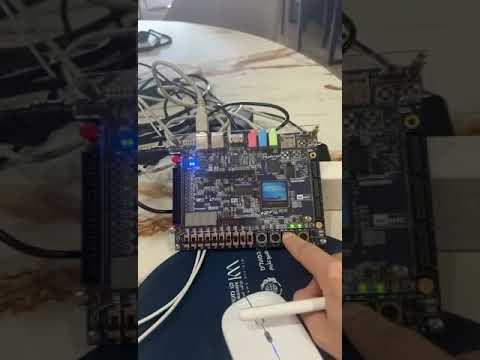
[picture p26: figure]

## סיכום: אפשר להגיד שהצלחנו לאמת את כל הסימולציות עשינו את המשימות כמו

שצריך .

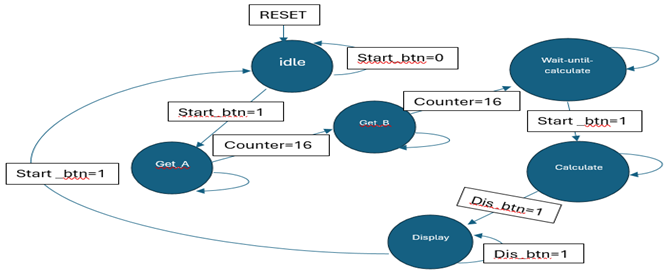
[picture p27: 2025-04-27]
assets/main_state_machine.png

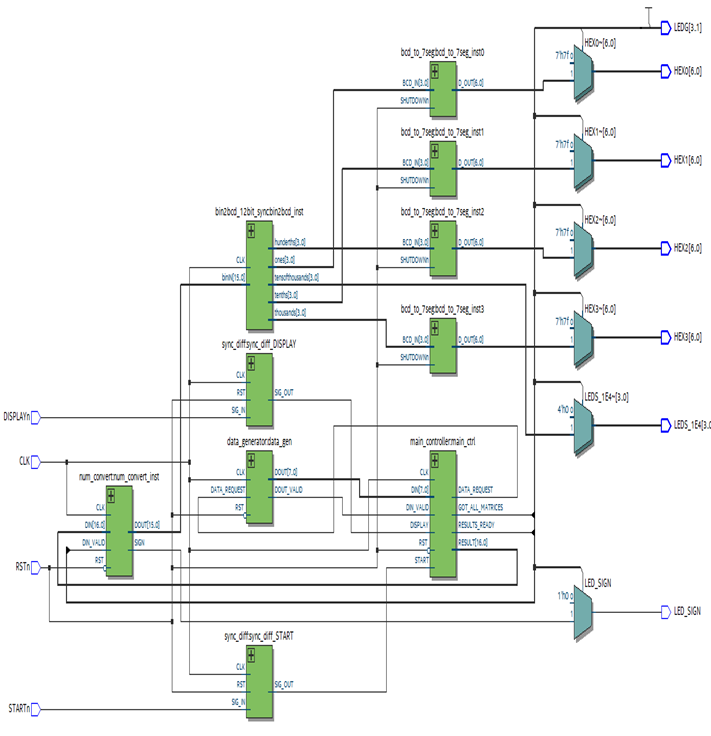
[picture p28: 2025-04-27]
assets/matrices_mult_block_diagram.png

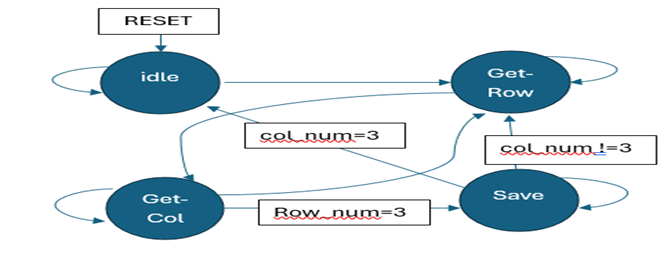
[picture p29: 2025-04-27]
assets/multiply_state_machine.png

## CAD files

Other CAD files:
synthesis/rst_btn_stp.stp
synthesis/display_btn_stp.stp
synthesis/start_btn_stp.stp
